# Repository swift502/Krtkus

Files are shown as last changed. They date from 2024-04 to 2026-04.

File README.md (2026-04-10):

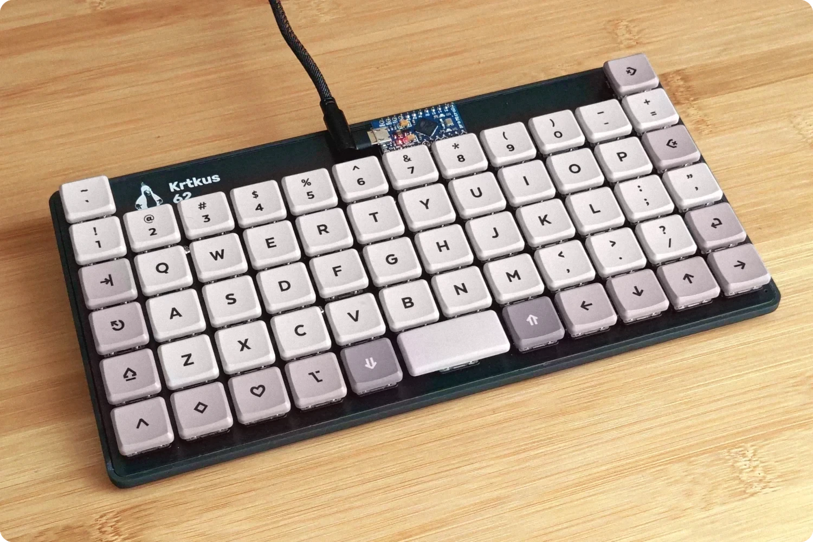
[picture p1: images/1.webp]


# Krtkus

> [!WARNING]
> Krtkus has been succeeded by [Krteq](https://github.com/swift502/Krteq), a much more complete design that's also easier to build. I recommend you check it out instead!

An extended 5x12 keyboard with 2 extra keys. The design is intended for ortho layouts with a shifted number row, allowing for the placement of the delete and tilde keys above their usual spots. PCBs are designed in Kicad, case in Blender.

- Low profile
    - Kailh Choc V1
    - Gateron KS-27/KS-33
- QMK/VIA compatible
- Tray mount
- 3D printed case with a 7 degree tilt
- 236mm × 122mm × 30mm

Connecting the keyboard to [usevia.app](https://usevia.app) requires manually uploading the [design file](production/krtkus_via.json) in the design tab.

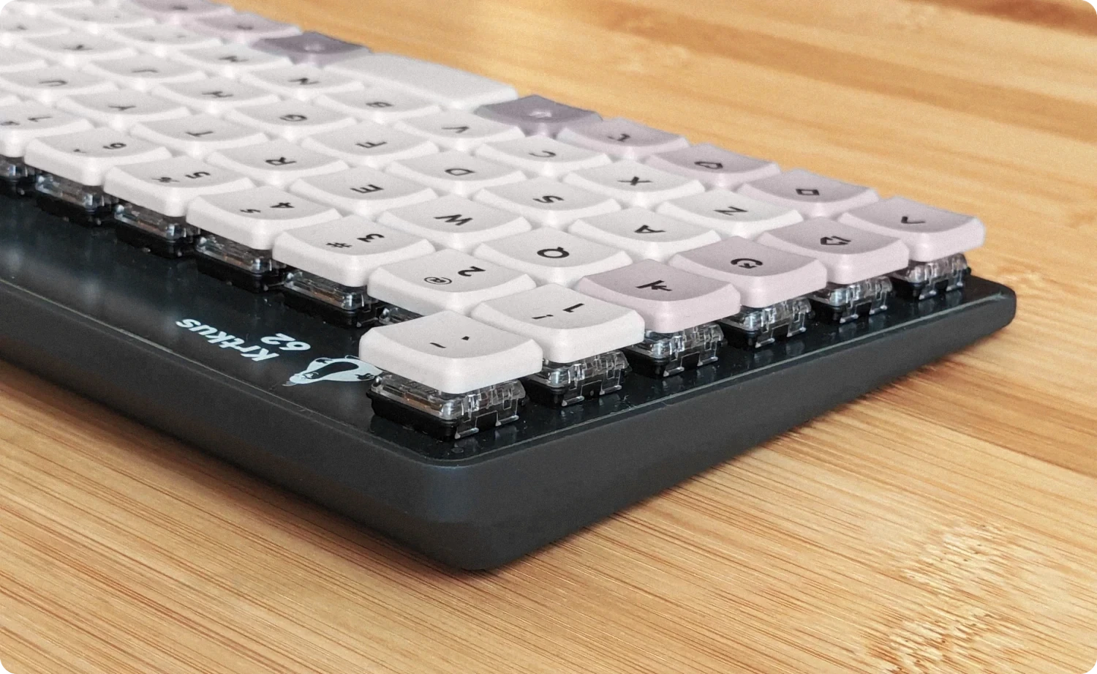
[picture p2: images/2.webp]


## Parts

- One of the PCBs:
    - [Choc V1](production/pcb_choc_v1)
    - [KS-33](production/pcb_ks_33)
- Case: 
    - [STL file](production/krtkus_case.stl)
- Arduino Pro Micro
- 61 SMD diodes
- 61 switches
- 61 keycaps
- 5 M2x6mm screws

#### Optional:

- 90 degree Micro-USB cable
- Rubber feet

## Room for improvement

- Spacebar stabilizer
- Num/Caps indicators
- LED matrix
- Hotswap version
- Standard USB port orientation
- Protect the MCU against dust

All of the above have been addressed by the successor [Krteq](https://github.com/swift502/Krteq).

## My builds

| Board | Keycaps | Switches | Case | Firmware |
| --- | --- | --- | --- | --- |
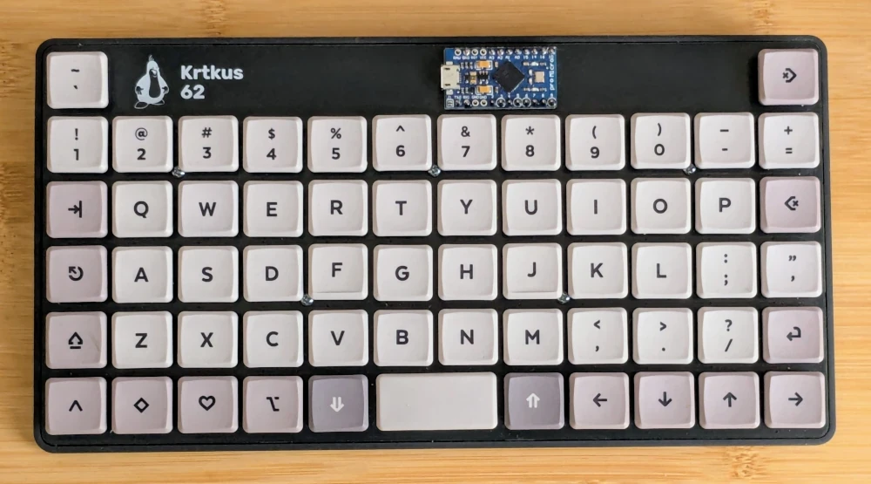
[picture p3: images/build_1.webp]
|  | MBK Legend Ergo/Ortho | Choc V1 Brown | Black Resin | Caterina |
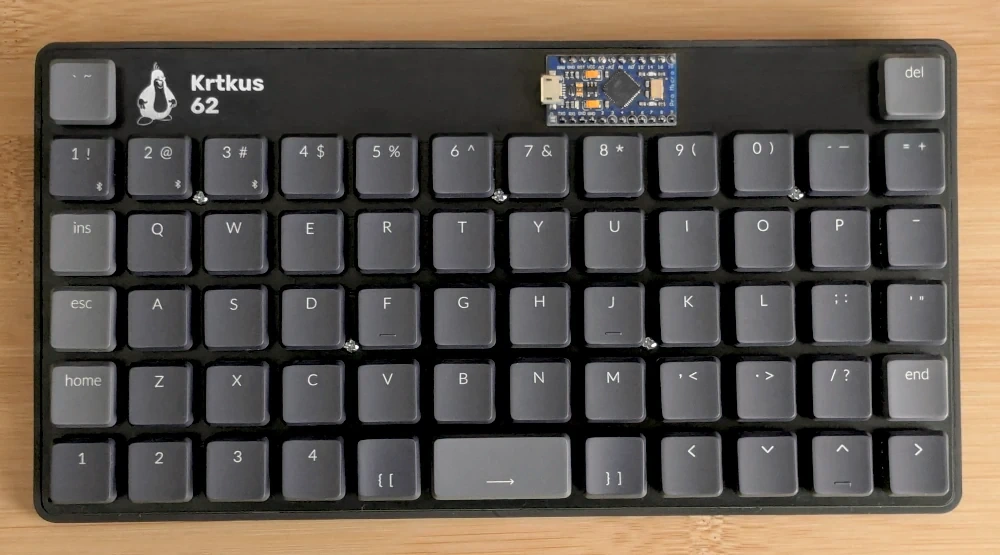
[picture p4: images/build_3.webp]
|  | Keychron LSA ABS | KS-33 Brown | Black Resin | Caterina |
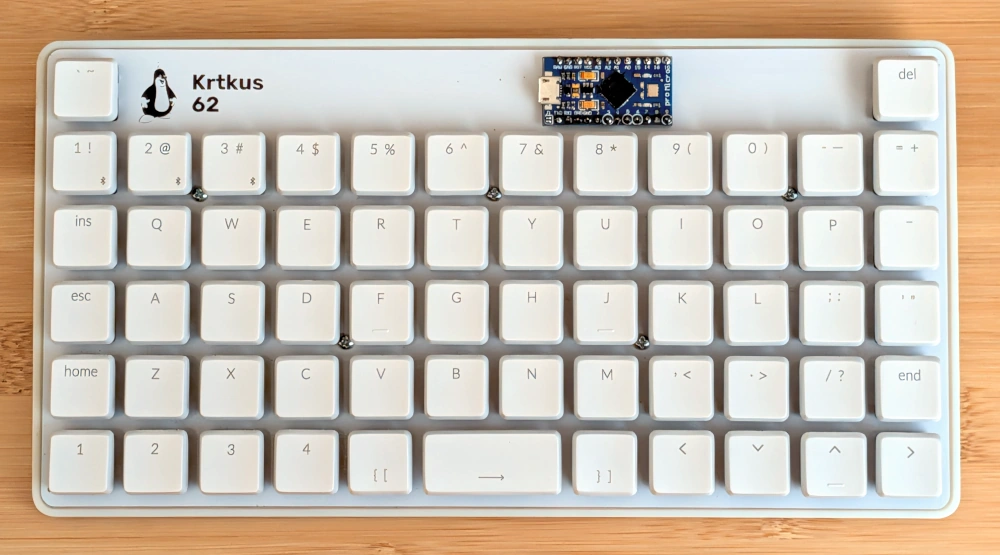
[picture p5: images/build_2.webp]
|  | Keychron LSA ABS | KS-33 Red | 9600 Resin | Caterina (Legacy) |
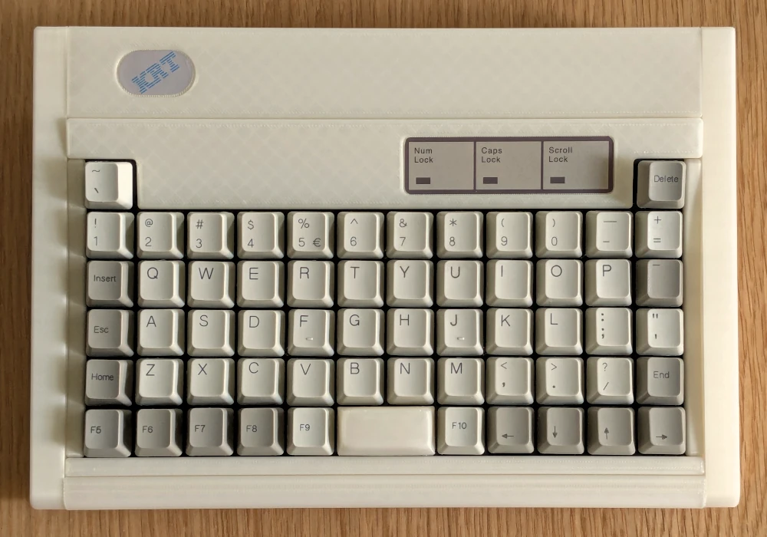
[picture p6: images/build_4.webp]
|  | Dell AT101W | KS-33 Banana | [Krtkus Retro](https://github.com/swift502/KrtkusRetro) | Caterina |

## QMK

Standard QMK setup except for `"tap_keycode_delay": 40`, which fixes ignored taps in some games where input scanning is tied to frame rate. To the best of my knowledge, keeping this value above 33ms (30fps) should cover all edge cases.

### Documentation

- `info.json` reference: https://docs.qmk.fm/reference_info_json
- Keycodes: https://docs.qmk.fm/keycodes

### Compiling (Windows)

- Python: https://www.python.org/
- MSYS: https://msys.qmk.fm
- Toolbox: https://qmk.fm/toolbox

Run the compile script:

```sh
python qmk_compile.py
```

### Resetting

Once the firmware is flashed, it provides key combinations to enter bootloader or clear the keyboard's persistent storage.

- <kbd>LShift</kbd> + <kbd>RShift</kbd> + <kbd>B</kbd> - Puts the keyboard into bootloader mode for flashing
- <kbd>LShift</kbd> + <kbd>RShift</kbd> + <kbd>C</kbd> - Clears EEPROM and reverts to the default keymap

## Kicad 8

### Libraries

Below is a list libraries included in the project. These libraries are not licensed under CC0. Please refer to each specific library for licensing details.

- [Scotto Kicad](https://github.com/joe-scotto/scottokeebs/tree/main/Extras/ScottoKicad)
- [MX V2](https://github.com/ai03-2725/MX_V2)
- [Gateron 3D models](https://www.gateron.com/pages/3d)

### Switch grid

| Unit | Offset |
| --- | --- |
| Switch | 19.05 |
| Switch 4 | 4.7625 |
| Switch 16 | 1.190625 |
| Switch 64 | 0.29765625 |

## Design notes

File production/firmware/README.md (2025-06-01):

# Firmware

Here you can find pre-compiled atmega32u4 firmware files, intended for the Pro Micro controller.

Most Pro Micros should run caterina, however if you encounter issues, you might want to try another bootloader.

The legacy firmware is only used for a specific version of the KS-33 PCB, which is no longer publicly available.

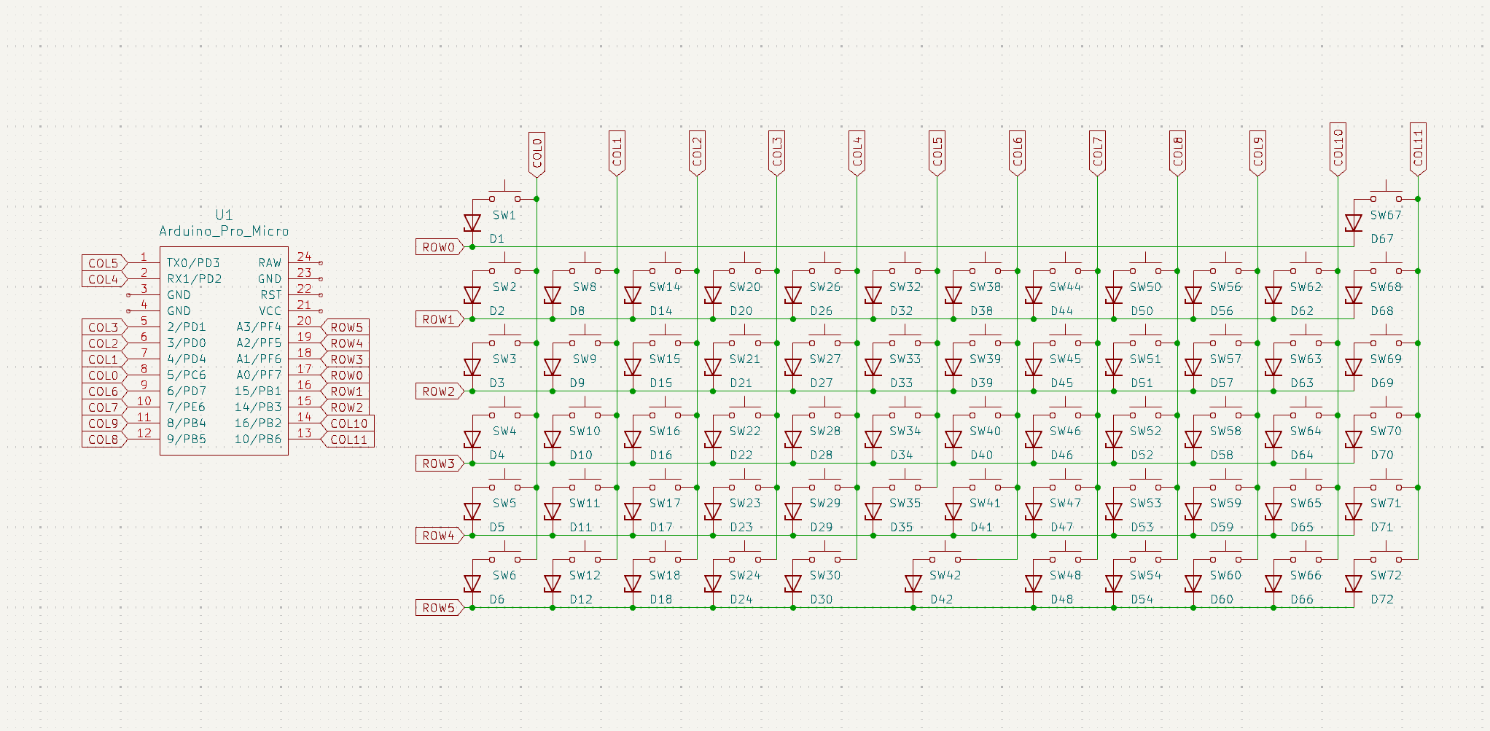
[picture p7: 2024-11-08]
images/schematic.png

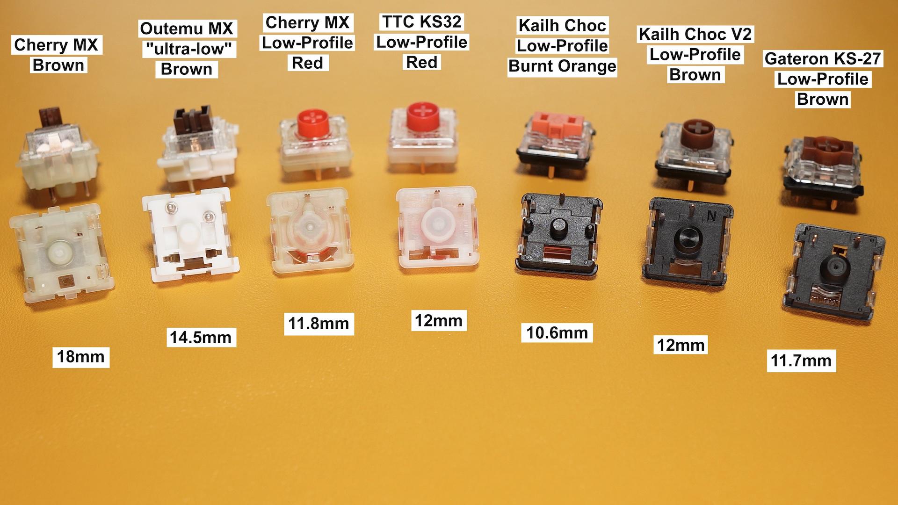
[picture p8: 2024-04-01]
images/switches.jpg

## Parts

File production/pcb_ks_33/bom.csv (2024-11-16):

Designator | Footprint | Quantity | Value | LCSC Part #
D1, D10, D11, D12, D14, D15, D16, D17, D18, D2, D20, D21, D22, D23, D24, D26, D27, D28, D29, D3, D30, D32, D33, D34, D35, D38, D39, D4, D40, D41, D42, D44, D45, D46, D47, D48, D5, D50, D51, D52, D53, D54, D56, D57, D58, D59, D6, D60, D62, D63, D64, D65, D66, D67, D68, D69, D70, D71, D72, D8, D9 | Diode_SOD-123 | 61 | 1N47xxA
SW1, SW10, SW11, SW12, SW14, SW15, SW16, SW17, SW18, SW2, SW20, SW21, SW22, SW23, SW24, SW26, SW27, SW28, SW29, SW3, SW30, SW32, SW33, SW34, SW35, SW38, SW39, SW4, SW40, SW41, SW42, SW44, SW45, SW46, SW47, SW48, SW5, SW50, SW51, SW52, SW53, SW54, SW56, SW57, SW58, SW59, SW6, SW60, SW62, SW63, SW64, SW65, SW66, SW67, SW68, SW69, SW70, SW71, SW72, SW8, SW9 | Gateron-KS33-Solderable-1U-Tight | 61 | Push
U1 | Arduino_Pro_Micro | 1 | Arduino_Pro_Micro

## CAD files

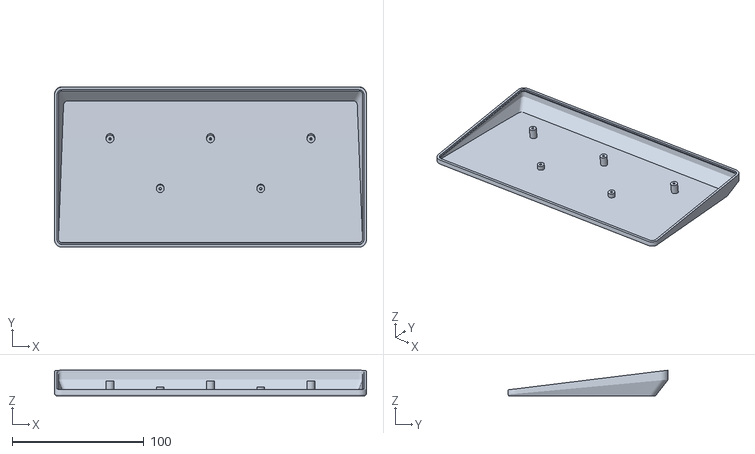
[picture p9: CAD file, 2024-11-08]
production/krtkus_case.stl
236.6 x 121.6 x 19.4

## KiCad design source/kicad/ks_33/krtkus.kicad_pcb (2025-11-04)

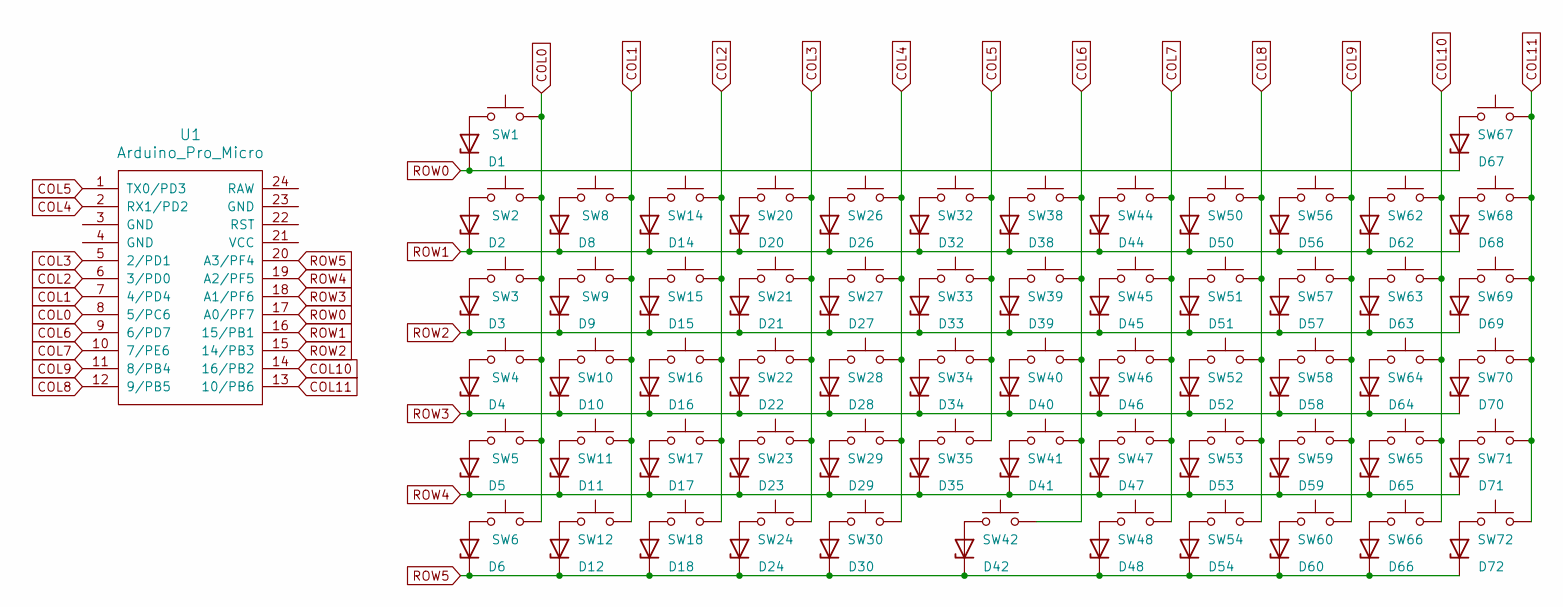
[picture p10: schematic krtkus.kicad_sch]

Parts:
D1, D2, D3, D4, D5, D6, D8, D9, D10, D11, D12, D14, D15, D16, D17, D18, D20, D21, D22, D23, D24, D26, D27, D28, D29, D30, D32, D33, D34, D35, D38, D39, D40, D41, D42, D44, D45, D46, D47, D48, D50, D51, D52, D53, D54, D56, D57, D58, D59, D60, D62, D63, D64, D65, D66, D67, D68, D69, D70, D71, D72: 1N47xxA; Diode_SOD-123
SW1, SW2, SW3, SW4, SW5, SW6, SW8, SW9, SW10, SW11, SW12, SW14, SW15, SW16, SW17, SW18, SW20, SW21, SW22, SW23, SW24, SW26, SW27, SW28, SW29, SW30, SW32, SW33, SW34, SW35, SW38, SW39, SW40, SW41, SW42, SW44, SW45, SW46, SW47, SW48, SW50, SW51, SW52, SW53, SW54, SW56, SW57, SW58, SW59, SW60, SW62, SW63, SW64, SW65, SW66, SW67, SW68, SW69, SW70, SW71, SW72: Push; Gateron-KS33-Solderable-1U-Tight
U1: Arduino_Pro_Micro

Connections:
COL0: SW1.2, SW2.2, SW3.2, SW4.2, SW5.2, SW6.2, U1.8 (5/PC6)
COL1: SW8.2, SW9.2, SW10.2, SW11.2, SW12.2, U1.7 (4/PD4)
COL2: SW14.2, SW15.2, SW16.2, SW17.2, SW18.2, U1.6 (3/PD0)
COL3: SW20.2, SW21.2, SW22.2, SW23.2, SW24.2, U1.5 (2/PD1)
COL4: SW26.2, SW27.2, SW28.2, SW29.2, SW30.2, U1.2 (RX1/PD2)
COL5: SW32.2, SW33.2, SW34.2, SW35.2, U1.1 (TX0/PD3)
COL6: SW38.2, SW39.2, SW40.2, SW41.2, SW42.2, U1.9 (6/PD7)
COL7: SW44.2, SW45.2, SW46.2, SW47.2, SW48.2, U1.10 (7/PE6)
COL8: SW50.2, SW51.2, SW52.2, SW53.2, SW54.2, U1.12 (9/PB5)
COL9: SW56.2, SW57.2, SW58.2, SW59.2, SW60.2, U1.11 (8/PB4)
COL10: SW62.2, SW63.2, SW64.2, SW65.2, SW66.2, U1.14 (16/PB2)
COL11: SW67.2, SW68.2, SW69.2, SW70.2, SW71.2, SW72.2, U1.13 (10/PB6)
unnamed: D1.2 (A), SW1.1
unnamed: D2.2 (A), SW2.1
unnamed: D3.2 (A), SW3.1
unnamed: D4.2 (A), SW4.1
unnamed: D5.2 (A), SW5.1
unnamed: D6.2 (A), SW6.1
unnamed: D8.2 (A), SW8.1
unnamed: D9.2 (A), SW9.1
unnamed: D10.2 (A), SW10.1
unnamed: D11.2 (A), SW11.1
unnamed: D12.2 (A), SW12.1
unnamed: D14.2 (A), SW14.1
unnamed: D15.2 (A), SW15.1
unnamed: D16.2 (A), SW16.1
unnamed: D17.2 (A), SW17.1
unnamed: D18.2 (A), SW18.1
unnamed: D20.2 (A), SW20.1
unnamed: D21.2 (A), SW21.1
unnamed: D22.2 (A), SW22.1
unnamed: D23.2 (A), SW23.1
unnamed: D24.2 (A), SW24.1
unnamed: D26.2 (A), SW26.1
unnamed: D27.2 (A), SW27.1
unnamed: D28.2 (A), SW28.1
unnamed: D29.2 (A), SW29.1
unnamed: D30.2 (A), SW30.1
unnamed: D32.2 (A), SW32.1
unnamed: D33.2 (A), SW33.1
unnamed: D34.2 (A), SW34.1
unnamed: D35.2 (A), SW35.1
unnamed: D38.2 (A), SW38.1
unnamed: D39.2 (A), SW39.1
unnamed: D40.2 (A), SW40.1
unnamed: D41.2 (A), SW41.1
unnamed: D42.2 (A), SW42.1
unnamed: D44.2 (A), SW44.1
unnamed: D45.2 (A), SW45.1
unnamed: D46.2 (A), SW46.1
unnamed: D47.2 (A), SW47.1
unnamed: D48.2 (A), SW48.1
unnamed: D50.2 (A), SW50.1
unnamed: D51.2 (A), SW51.1
unnamed: D52.2 (A), SW52.1
unnamed: D53.2 (A), SW53.1
unnamed: D54.2 (A), SW54.1
unnamed: D56.2 (A), SW56.1
unnamed: D57.2 (A), SW57.1
unnamed: D58.2 (A), SW58.1
unnamed: D59.2 (A), SW59.1
unnamed: D60.2 (A), SW60.1
unnamed: D62.2 (A), SW62.1
unnamed: D63.2 (A), SW63.1
unnamed: D64.2 (A), SW64.1
unnamed: D65.2 (A), SW65.1
unnamed: D66.2 (A), SW66.1
unnamed: D67.2 (A), SW67.1
unnamed: D68.2 (A), SW68.1
unnamed: D69.2 (A), SW69.1
unnamed: D70.2 (A), SW70.1
unnamed: D71.2 (A), SW71.1
unnamed: D72.2 (A), SW72.1
ROW0: D1.1 (K), D67.1 (K), U1.17 (A0/PF7)
ROW1: D2.1 (K), D8.1 (K), D14.1 (K), D20.1 (K), D26.1 (K), D32.1 (K), D38.1 (K), D44.1 (K), D50.1 (K), D56.1 (K), D62.1 (K), D68.1 (K), U1.16 (15/PB1)
ROW2: D3.1 (K), D9.1 (K), D15.1 (K), D21.1 (K), D27.1 (K), D33.1 (K), D39.1 (K), D45.1 (K), D51.1 (K), D57.1 (K), D63.1 (K), D69.1 (K), U1.15 (14/PB3)
ROW3: D4.1 (K), D10.1 (K), D16.1 (K), D22.1 (K), D28.1 (K), D34.1 (K), D40.1 (K), D46.1 (K), D52.1 (K), D58.1 (K), D64.1 (K), D70.1 (K), U1.18 (A1/PF6)
ROW4: D5.1 (K), D11.1 (K), D17.1 (K), D23.1 (K), D29.1 (K), D35.1 (K), D41.1 (K), D47.1 (K), D53.1 (K), D59.1 (K), D65.1 (K), D71.1 (K), U1.19 (A2/PF5)
ROW5: D6.1 (K), D12.1 (K), D18.1 (K), D24.1 (K), D30.1 (K), D42.1 (K), D48.1 (K), D54.1 (K), D60.1 (K), D66.1 (K), D72.1 (K), U1.20 (A3/PF4)

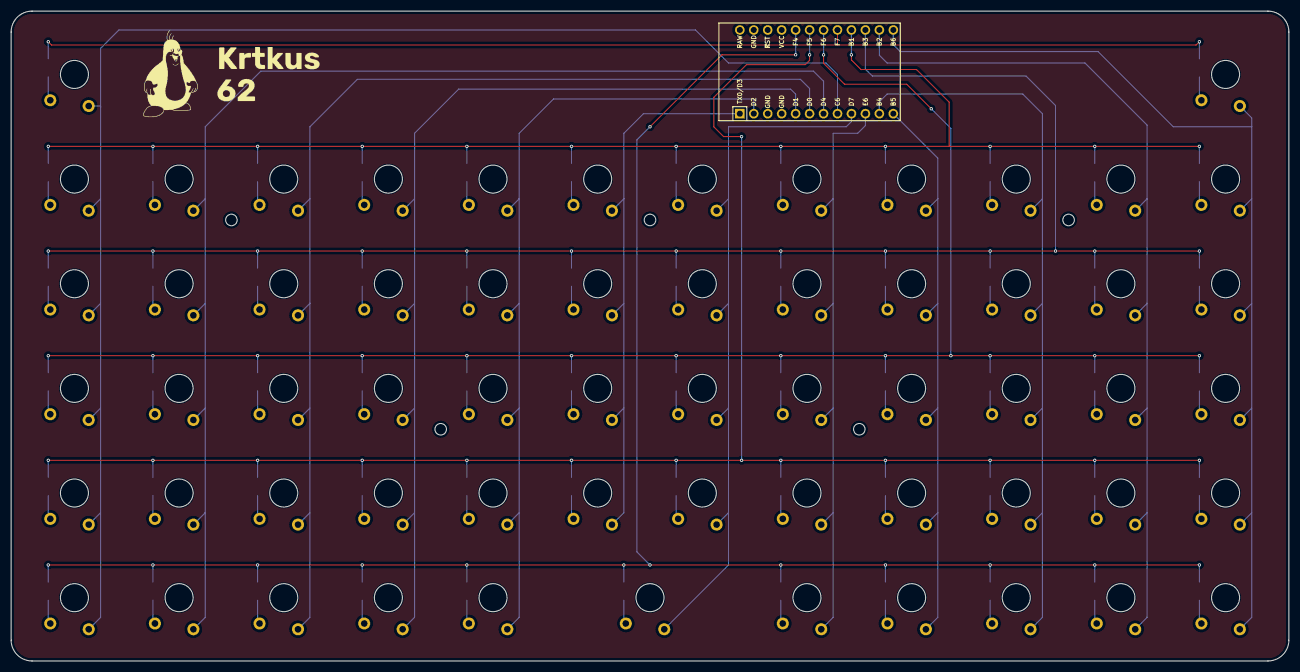
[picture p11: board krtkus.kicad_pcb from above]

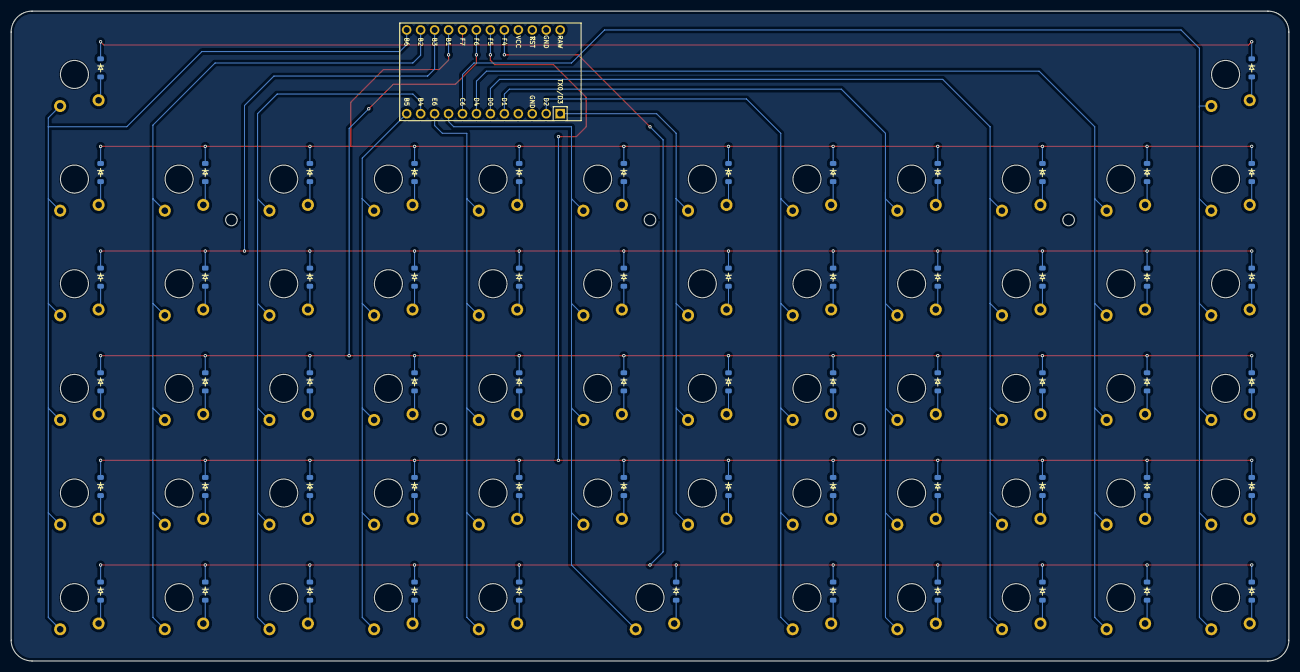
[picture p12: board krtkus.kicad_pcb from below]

Board: 2 copper layers, 232.6 x 118.3 mm, 123 parts (61 on the bottom side), 79 nets.

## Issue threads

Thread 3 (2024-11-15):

Hotswap + alternate MCU?

bnorick, 2024-11-15:
I love the design, great work! A couple things that would really take it over the top for me, namely the ability to use hotswap sockets and the ability to make it wireless. I'd love to use a Seeed XIAO BLE (like TOTEM) along with two daisy chained shift registers (74hc595) which would be needed in order to get enough pins for the matrix.

I know there are a lot of learning resources available in this space and I started to have a look at them in order to work on this project, but before I went further into the rabbit hole I wanted to get your opinion. Is this a fools errant?  Have you already considered and/or started on any changes like these? Any other input?

Thanks!

swift502, 2024-11-15:
Hi! Glad you like the board. 👌

1. I originally wanted hot swap, because I thought I could get JLCPCB to solder them for me. But that's very impractical, so I just ditched hotswap altogether, because it would just mean spending extra money on the sockets.
But obviously it's possible, just needs rewiring of the pcb. I would do that if there was more interest. But right now you'd have to do that yourself. In kicad.

2. As for the controller, that sounds a little advanced for me. I don't know anything about daisy chaining and stuff. You'll have to redesign the whole PCB, and rebuild the qmk firmware - change the controller type and cols/rows pin identifiers.
So it's possible but those are very extensive changes. You'd almost be better off starting from scratch, because you'd be rewiring the whole PCB.

swift502, 2024-11-23:
Feel free to reopen if you have any more questions. 👌

Closed 2024-11-23.

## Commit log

2024-04-02 pi traces
    [keyboard.kicad_pcb, keyboard.kicad_sch]
2024-04-02 filled zone
    [keyboard.kicad_pcb]
2024-10-14 S67 fix
    [keyboard.kicad_pcb, keyboard.kicad_sch]
2024-10-14 path tweaks
    [keyboard.kicad_pcb]
2024-10-15 case v1
    [case.stl, keyboard.kicad_pcb]
2024-10-15 case v2
    [keyboard.kicad_pcb]
2024-10-16 case v3
2024-10-16 holes rework, case v4
2024-10-16 case origin
2024-10-16 production edits
    [case.stl, keyboard.kicad_pcb]
2024-10-18 production, readme
    [bom.csv, designators.csv, positions.csv]
2024-10-18 remove switch labels
    [bom.csv, keyboard.kicad_pcb, keyboard.kicad_sch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]
2024-10-18 through hole
    [bom.csv, keyboard.kicad_pcb, keyboard.kicad_sch]
2024-10-19 case update
    [case.stl]
2024-10-30 project structure
    [bom.csv, designators.csv, keyboard.kicad_pcb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]
2024-10-31 case supports fix
2024-11-03 case export
    [krtkus_case.stl]
2024-11-06 schematic images
2024-11-16 ks-33 footprint tweaks
    [bom.csv, krtkus.kicad_pcb, krtkus.kicad_sch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]
2025-03-07 libraries refactor
    [krtkus.kicad_pcb, krtkus.kicad_sch]
2025-03-21 color temperature
2025-05-30 case cleanup
2025-11-04 pcb build update
    [krtkus.kicad_pcb]
